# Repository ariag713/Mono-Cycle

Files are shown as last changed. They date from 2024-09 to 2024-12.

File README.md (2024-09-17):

# Mono-Cycle

## Description
  The monocycle will be a remote controlled unmanned vehicle (drone), that will drive on one wheel.
  Realistically the entire build will be a wheel with electronics in it.
  The drone will be able to balance on its own while stationary and in movement.
  The drone will be built in three main assemblies
  * The drive wheel
    * A ring gear with teeth on the inside of the ring and on the outside of the ring will be a layer of rubber or 3d printed filamnent (that has some spring to it)
    * The outside of the ring will have rounded edges to simulate a bicycle wheel. This will also help in cornering and turning
  * The drive housing
    * The drive housing is what is going to store all the electronic components that allow this vehicle to move.
    * The drive motor will rotate the tread around the drive housing to allow the drone to move.
    * It will also hold some support gears to keep the tread from slipping, and provide required tension to the tread to also prevent it from slipping
    * It will also house the gyroscopic actuator that will allow the unit to have controlled tilt
  * The load housing
    * for the final product, the load housing will be important for its practical usage.
    * The load housing will have the components required to keep the load balanced while the drone is in operation.
    * It will help mitigate the roll the load will receive upon acceleration and deceleration/braking.

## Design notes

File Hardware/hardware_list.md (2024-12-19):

*Here is the list for the Hardware component*
# Hardware
* Measurement: 20 inchs height
* Jump wires and solid core wires

### Craft
* Controller
  * [Mobile device with access to Arduino Bluetooth Controller](https://play.google.com/store/apps/details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)
* Housing:
  * [3d printed - using whole roll of filament](https://www.amazon.com/ELEGOO-Filament-Dimensional-Accuracy-Cardboard/dp/B0BM739JRF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) -price: $19.99
* Power Supply:
  * Primary: 
    * [6 AA battery pack](https://www.amazon.com/Coppertop-Batteries-Ingredients-Long-lasting-Household/dp/B000IZQO7U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) - price: $7.29
  * Secondary:
    * [Li battery pack for boost module and recharging](https://www.amazon.com/Replacement-Bluetooth-Controller-Generation-Playstation-4/dp/B07K8C6HGT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) - price: $ 13.39
    
* Boost Module:
  * [MT3608](https://www.amazon.com/Converter-Adjustable-Voltage-Regulator-Compatible/dp/B089JYBF25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) - price: 6.99
   * Specifications:
    * Input Voltage: DC 2V-24V
    * Output Voltage: DC 5V-28V
    * Maximum Output Current: 2A
    * Maximum Conversion Efficiency: 93%
    * Board Size: 36 X 17 X 14mm/1.42 X 0.67 X 0.55inch(L*W*H) 
* Microcontroller:
  * [Arduino Uno R3](Datasheets/ArduinoR3-datasheet.pdf) -price: 16.99
* DC Motor:
   * [DC motor with gearbox](https://www.amazon.com/dp/B08CMPBXNL?ref=ppx_yo2ov_dt_b_fed_asin_title&th=1) - price: 9.99
    * Specifications:
     *  Brand: 	‎Gebildet
     * Weight: 8.47 Ounces
     * Dimmensions: 0.86"W x 0.86"H
     * Operating voltage: 3V~12VDC
     * Type: 1:48 gear ratio
* Transciever
   * [HC-05 Bluetooth Module](Datasheets/HC-05_Datasheet.pdf) - price: $9.99

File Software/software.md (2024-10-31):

*Here is the list for the software*
# Software
- PC Software:
  * Arduino IDE:
    * The Arduino IDE is a cross-platform application used to write, compile, and upload code to Arduino boards. It features a simple             interface for writing C/C++-based "sketches," with a code editor, syntax highlighting, and a serial monitor for debugging. The IDE 
      includes a library manager for additional functions and simplifies programming by providing pre-written libraries and easy USB 
      uploads to the board.
      
- Mobile Software
  * Arcuino Bluetooth Controller
    * The Arduino Bluetooth Controller App allows wireless control of Arduino     projects via Bluetooth from an Android device. It 
      supports multiple modes, such as button, joystick, and terminal, enabling users to send commands to control motors, lights, or other 
      connected components. Ideal for remote control, robotics, or home automation projects, it simplifies Bluetooth communication with 
      Arduino using modules like HC-05.

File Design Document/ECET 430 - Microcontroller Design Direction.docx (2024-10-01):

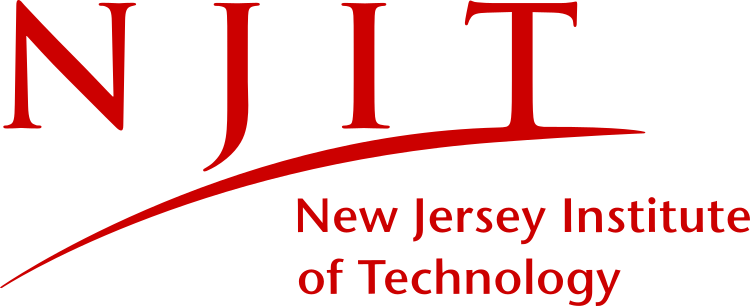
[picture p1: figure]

# Microcontroller Design Direction

Christian Hansis

Students:

Arturo Garcia

Joao Sarmiento

Jeury Abreu

2024-09-31

# Microcontrollers:

## 1. Arduino Uno:

- Arduino UNO is a microcontroller board based on the ATmega328P. It has 14 digital input/output pins (of which 6 can be used as PWM outputs), 6 analog inputs, a 16 MHz ceramic resonator, a USB connection, a power jack, an ICSP header and a reset button.

## 2. S32:

- The S32 chip refers to a family of microcontrollers and processors developed by NXP Semiconductors, designed specifically for automotive, industrial, and safety-critical applications. The S32 family is known for its high-performance, real-time capabilities and its support for automotive-grade standards such as ISO 26262.

## 3. ESP 32:

- ESP32 is a chip that provides Wi-Fi and (in some models) Bluetooth connectivity for embedded devices – in other words, for IoT devices. While ESP32 is technically just the chip, the modules and development boards that contain this chip are often also referred to as “ESP32” by the manufacturer.

# Pros and Cons:

## Arduino Uno (Atmega328P):

Pro | Con
Beginner Friendly | Limited Processing Power (Single-Core 16MHz)
Versatile and Well-Supported | Limited Memory(2KB SRAM, 32KB Flash, 1KB EEPROM)
Affordable | No Built-in Wi-Fi or Bluetooth
Extensive Shield Ecosystem | Limited I/O Pins
Open-Source Hardware and Software | No Real-Time Operating System (RTOS)
Low Power Consumption | Not Ideal for Resource Heavy Projects
USB Powered

## S32:

Pro | Con
Automotive-Grade Quality | High Complexity
High Performance | Higher Cost
Scalability | Overkill for Non-Automotive Applications
Real-Time Processing | Development Complexity
Advanced Security Features | Longer Development Cycle
Power Efficiency | Power Consumption in High-Performance Modes
Wide Ecosystem Support | Limited Availability in Consumer Markets

## ESP32:

Pro | Con
Wi-Fi and Bluetooth Connectivity | Complexity
Dual Core Processor | Limited Pin Availability
Low-Cost | Limited Ram (520 KB SRAM)
GPIO and Peripheral Support | Overheating Under Heavy Load
Low Power Consumption modes | High Power Consumption in Active Mode
Open Source SDK | Steeper Learning Curve
Built-in Security Features | Software Complexity

# Decision:

- Our decision is to use the Arduino Uno for our Mono-wheel as it is a good choice for simple, small-scale projects, especially for beginners due to its affordability, ease of use, and extensive community support. It’s ideal for basic tasks, low-power applications, and projects that don't require significant processing power, memory, or multitasking.

# Use of Resources from Microcontroller:

### 1. Motor Control (PWM via Timer):

Resource: Digital I/O Pins (PWM Capable), Timer1

#### PWM Parameters for Mono-Wheel Motor:

- Duty Cycle: The duty cycle controls the speed of the mono-wheel motor by adjusting the average voltage supplied to the motor. The duty cycle is a percentage of time the signal stays HIGH (on) versus LOW (off).
  - Initial Duty Cycle: Start with 50% (0.5) for testing.
  - Adjustable Duty Cycle: Can range between 0% (full stop) to 100% (full speed).
- Frequency: The frequency determines how fast the PWM signal switches between HIGH and LOW.
  - For motor control, a typical frequency is in the range of 500 Hz to 1 kHz, as lower frequencies can cause the motor to produce audible noise.
  - Chosen Frequency: 1 kHz for smoother motor control and less noise.

#### Arduino Uno PWM Pin:

- The use pin D9, which is one of the PWM-capable pins connected to Timer1. Timer1 is 16-bit, so it gives better control over the PWM signal compared to Timer0 and Timer2, which are 8-bit.

2. Direction Control (Digital Output Pins):

Resource: Digital I/O Pins (GPIO)

- The motor’s direction will be controlled by an H-Bridge driver ( L298N), which requires two digital pins to set the direction (forward or backward).

#### Pin Assignment for Direction Control:

- Pin D7: Forward direction
- Pin D8: Reverse direction

#### Parameters:

- The logic for these pins is binary:
  - Forward: D7 = HIGH, D8 = LOW
  - Reverse: D7 = LOW, D8 = HIGH

### 3. Sensor Feedback (Analog Input for Stability):

Resource: Analog I/O Pins

- For the mono-wheel’s balance and stability, I will use an IMU (Inertial Measurement Unit) or accelerometer/gyroscope combination, connected to the analog inputs.

#### Pin Assignment:

- Pin A0 and A1: Used for analog input from the IMU (for X and Z axis).

#### Parameters:

- The IMU will provide feedback on the tilt and orientation of the mono-wheel. This data will be used to adjust the motor speed and direction to maintain balance.

### 4. User Input (Potentiometer for Speed Control)

Resource: Analog Input or Digital Input

- A potentiometer will allow the user to manually control the speed of the mono-wheel by adjusting the PWM duty cycle.

#### Pin Assignment:

- Pin A3: Analog input for the potentiometer (speed control).

#### Parameters:

- The potentiometer will adjust the motor speed by changing the duty cycle of the PWM signal.
- Output Voltage Range: 0-5V (corresponds to 0%-100% duty cycle).

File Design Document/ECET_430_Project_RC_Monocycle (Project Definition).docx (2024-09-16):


# ECET 430 -

# Remote Controller Monocycle

Christian Hansis

Students:

Arturo Garcia

Joao Sarmiento

Jeury Abreu

2023-08-24

# Client

- contact information.-
  - Arturo Garcia
    - arg68@njit.edu
    - 856-558-0271

Joao Sarmiento

    - js2669@njit.edu
    - 201-772-9021

Jeury Abreu

    - ja528@nit.edu
    - 732-925-7059

# Communication

Regarding communication we as a team have our own discord chat where we discuss anything relating to our project. We created a todo list to make sure that we are going in the same path and also clarifying any dude or concern, also to make easy for us in what part are working or what is missing, for this last feature mentioned we are using Github In addition, we are filling all the stuff regarding hardware even software in our team Github logbook

# Objectives

DESCRIPTION:

Our product is basically inspired by a MIB (Men in Black) vehicle. The concept of this product is similar to that vehicle, it is a self-stabilized unicycle where the active driving area is around the payload/core of the cycle and it is also manageable by a remote control which will play a crucial role in the performance of our product. The particularity of the design which demonstrates the innovation in our product itself and also brings a new idea to the public. To add, this product is aimed at people of any age. We have in mind to create two models, the first one in mind would be the simplest implemented for the aforementioned, and the second would provide certain features such as a camera and a speaker included to connect Bluetooth equipment and also the remote control would also have variations such as the implementation of a screen in it, basically, assimilating the functions of a drone.

# Scenario

## User Interaction Stories

When you receive your product basically you will get a very detailly box with images referring to our product. When you open it, you will see the remote controller packed in its own box, inside it it will be covered with a bubble bag, then you will find the monocycle also inside in a separate box and also cover for a bubble bag. Besides, you will also find a manual, this will guide you on how to use it and how to install the batteries for the monocycle and the remote controller, the basics functionalities and the proper ways to use it. Relating to use, once you put the batteries on product and remote controller you will manipulate thru RC the product, it basically gives you the entertainment of a RC car, But the difference or the fun part here will be to see how it moves forward or backward and even when it makes turns, that is what makes it innovative and outstanding compared to conventional RC cars. Regarding troubleshooting, if an problem exists the product contains replacement for the wheel, and for the RC, in the manual explain how replace the damage part, is not too difficult to solve by ourselves, in addition, the product have a 1 year guarantee which cover any problem relate to RC or the product itself.

## User Interface

In terms of user interface, as mentioned before our product will have two versions, one with a display in the controller and the other without it. Basically, both versions in the remote controller will not have a button, but it will have a joystick whose functionality will consist in guiding the craft to the direction desired, also will count with an on/off switch for craft and controller. Also an indicator will be added as a proof that the craft is on or off also the controller will have one with the same functionality.

# User Acceptance

- Given-When-Then criteria
  - when craft is active,it should auto balance
- quantifiable goals

# Parameters

## Technical

- dimensions .- 21x10x5 cm or 8.3x3.9x2 in
- weight.- 500g or 1.1 pound
- Electromagnetic compatibility (EMC) and electromagnetic interference (EMI)
- protection

## Functions

Our product will have main functions that will make it a unique model, the main functions are self-balancing, with this function it will be easier to manipulate and handle it with this functionality it will provide greater comfort and fun to the user. The other function is to be able to get up again after a fall, this function is basically when the user collides with a structure, after the impact the vehicle will return to its initial position. Another function is the ability to go forward and backward, either for the comfort of the user. Our product offers the ability to go forward and backward correctly to provide a great maneuverability experience of our product. The other function of this product is to keep the load (core) stable and the track is what moves, this means that while the vehicle is in motion the core and what is inside it will remain stable while the tire or belt that surrounds it is what moves. and the last function refers to the automatic accelerator and manual accelerator options, this is basically to provide greater entertainment to the user who, if he wants can accelerate with the remote control or the vehicle itself can accelerate on its own.

## Integration

Interface

it counts with a bluetooth system incorporated and also a remote controller which will be the mechanism to make it work. (app?)

## Operational

- restrictions. - No restrictions
- duty cycle. - The battery life expectation of our product is 7 hours after charge, and the charge process of it is around 2 to 3 hours to fully charge.

## Regulatory

- laws
- regulations
- policies

## Life Cycle

- manufacturing.-
- programming
- tracking
- service
- associated services

# Environment

Our product has the ability to work in different types of environments, the temperature ranges in which it will work are between 14 degrees Fahrenheit and 110 degrees Fahrenheit, below 14 degrees Fahrenheit it might not work very well due to the low temperature which damages some cables, the same happens in temperatures above 110, some cables and components may start to melt.The product should avoid smooth surfaces as it will be difficult to drive properly and could also damage the core due to the constant dangers of falling due to these surfaces. Also, as an electronic device, you should avoid water as water will destroy all the internal components and render it useless.

- power.- it will count with a 4V 1200mAh Li-Ion Battery implemented to the craft. The purpose of using this battery is that it is reliable, very durable, easy to get a replacement and also easy to replace.

# Starting Point

- existing prototypes

https://www.instructables.com/Making-a-Monowheel/

In the link above is a prototype of our project but on a big scale and using foundations of mechanics, basically from this we just use the idea of how our project will look.

https://youtu.be/fIADzTanDo8?si=Uh0wI1ux-ViAeKzg

And from this link we will get an idea of how to use the appropriate wiring and how our project will work and the functionalities it will have. In addition, we will add the rest of the elements mentioned above to give it a different and innovative look.

# Key Concerns

The most important thing that we can observe in our product is basically what refers to self-balancing, it is possibly the most important feature that we can appreciate, another one that we could talk about is the distance between the remote control antenna and the vehicle receiver, they can communicate with each other for a better experience, another important point is the sideways turn or rather the turns, and the self-balancing also depends a lot on this, which would allow the product to have perfect stability and avoid any unforeseen event when trying to turn right or left or a total turn (180 or 360 degrees)

# Future

- plans
- ideas

# Glossary

- common vocabulary
- project specific terms

# Open Questions

to be discussed with team/clien

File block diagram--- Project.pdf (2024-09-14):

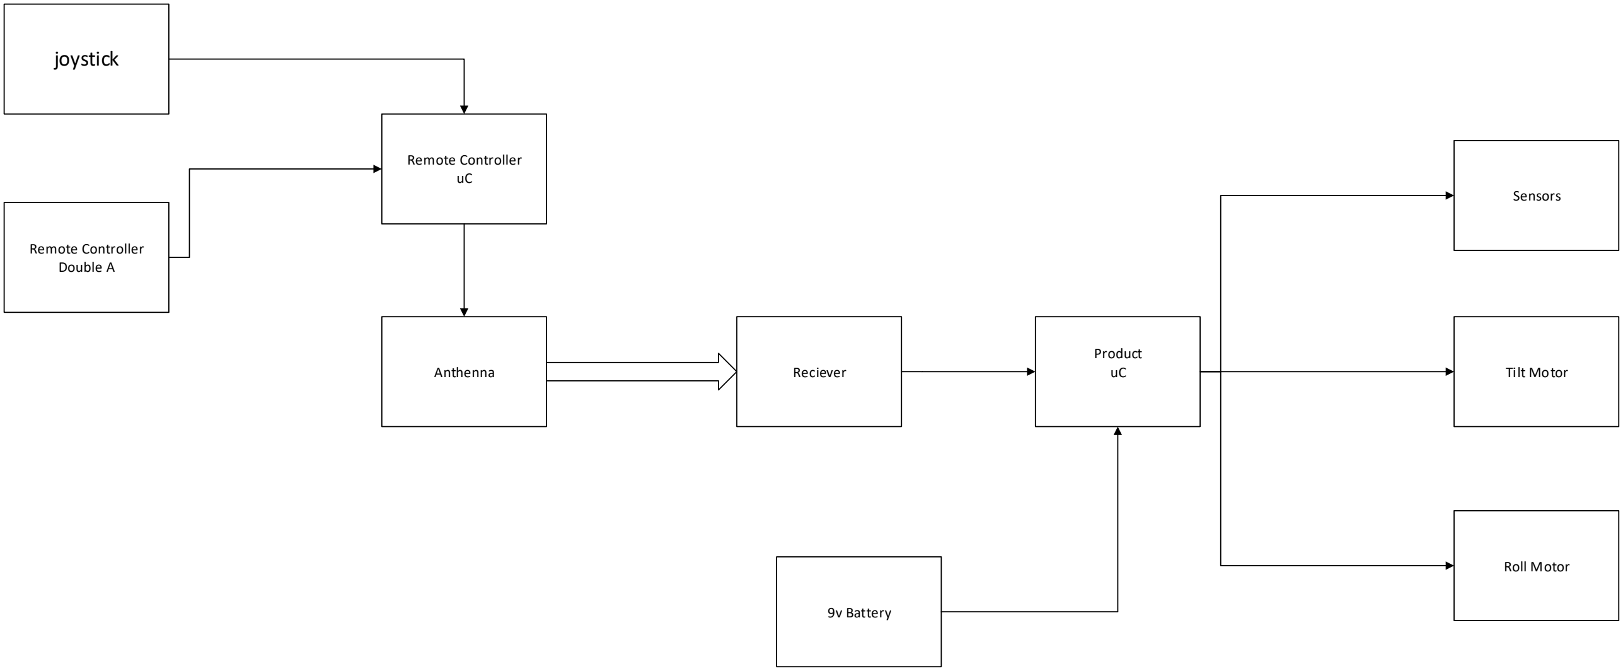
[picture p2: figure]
joystick; Remote Controller uC; Remote Controller Double A; Anthenna; Sensors; 9v Battery; Product; Reciever; Tilt Motor; Roll Motor

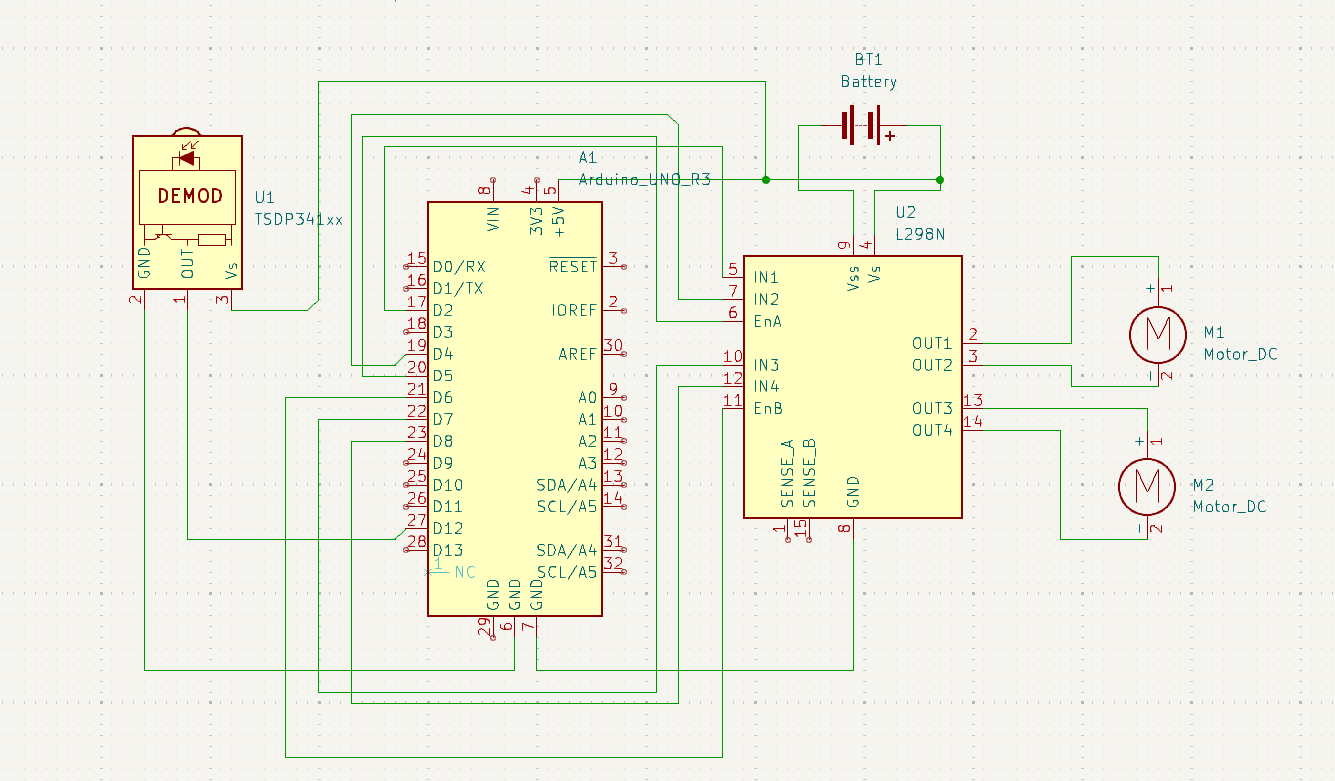
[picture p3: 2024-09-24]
schematics/v1.0/Craft_Schematic.png

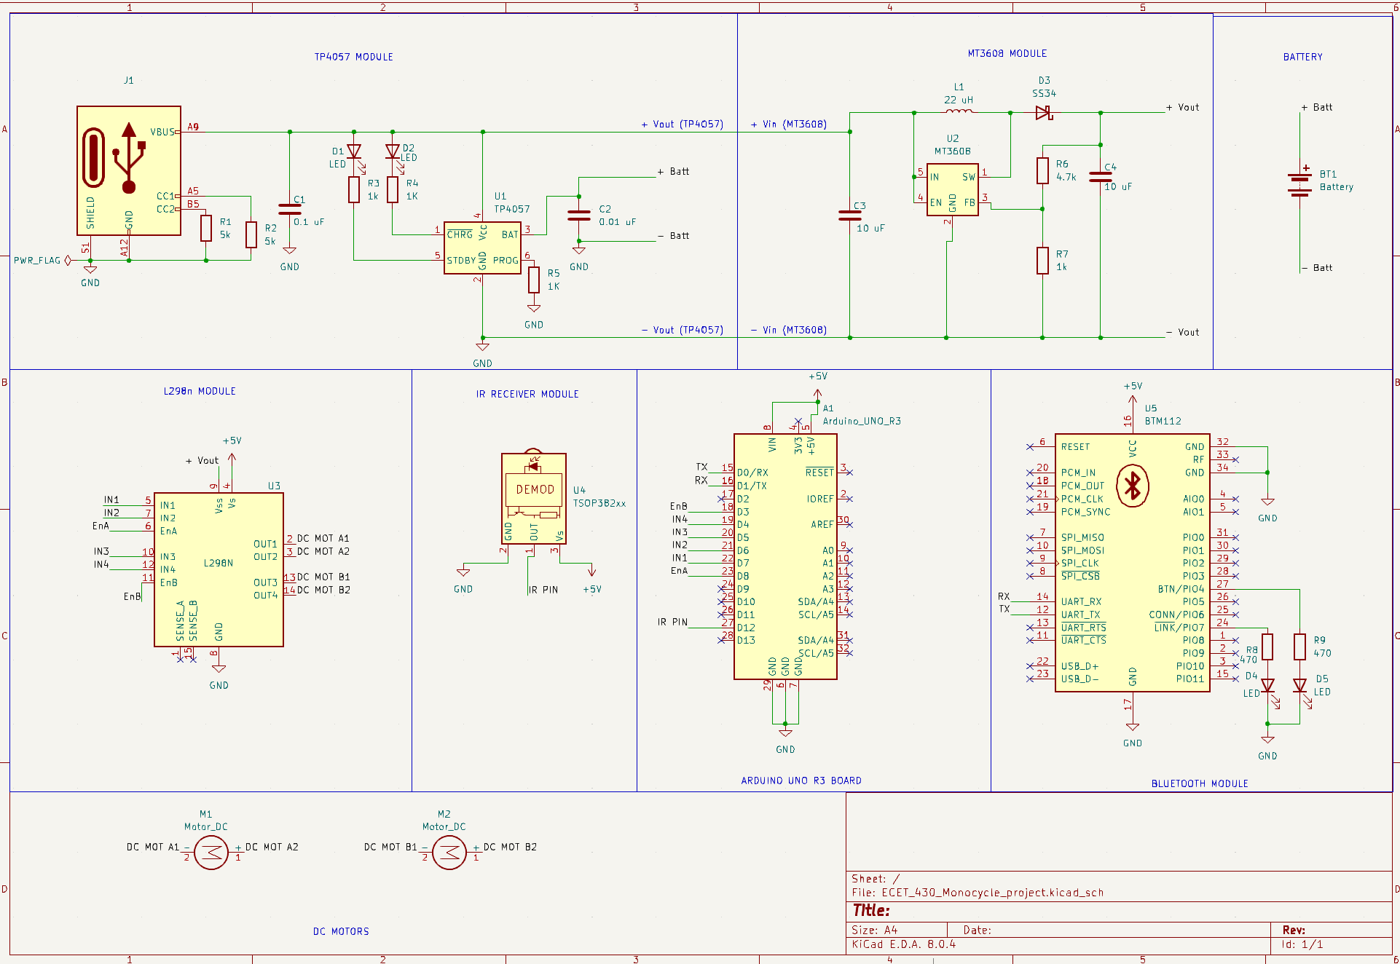
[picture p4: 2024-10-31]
schematics/Monocycle1.5/Monocycle_Project_Schematic.png

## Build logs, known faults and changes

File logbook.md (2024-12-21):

# Logbook

## Mono-Cycle Project

### **09/10/24**
- Defined the project scope and objectives for the Monocycle. Outlined the functional and performance requirements to ensure clarity of the project goals.

### **09/16/24**
- Major moving parts for the Monocycle were carefully selected based on durability, performance, and compatibility with the design specifications.

### **09/24/24**
- Created the initial schematic for the microcontroller, focusing on the basic circuit design to support motor control and integration with peripheral components.

### **09/27/24**
- Procured key components including DC motors and an H-bridge motor driver. These arrived and were prepared for integration and testing with the microcontroller.

### **10/08/24**
- Conducted preliminary tests on the motors to evaluate their basic movements. Using a serial monitor, verified forward, backward, left-turn, and right-turn functionalities.

### **10/15/24**
- Concluded the motor movement tests successfully. All directions and functionalities performed as expected, confirming the motors and driver were operational.

### **10/17/24**
- Updated the schematic to include new components: a booster module to regulate voltage, an HC-05 Bluetooth module for wireless control, and a type-C battery charger for efficient power management.

### **10/21/24**
- Integrated the booster module into the circuit to raise the voltage to 10V using a voltage regulator. Also connected a battery charger to streamline the power supply system.

### **10/29/24**
- Began the look-like design phase in Autodesk Fusion, focusing on creating a model that resembles the final product. Continued material selection for construction and assembly.

### **11/04/24**
- Implemented the HC-05 Bluetooth module with Arduino for wireless motor control. Wrote and ran code to integrate the L298N motor driver, enabling PWM control for precise motor speed adjustments.

### **11/10/24**
- Started configuring the HC-05 Bluetooth module for serial communication with Arduino. During testing, identified an issue where the booster module was not supplying adequate current.
- Planned to replace the power supply with a higher-current battery setup (6 AA batteries in series) to resolve the issue.

### **11/12/24**
- Designed the initial monowheel housing. After peer review and discussion, identified areas for improvement, leading to plans for redesign.
- Replaced the power supply with a battery pack of 6 AA batteries to meet the current requirements of the motor driver.

### **11/19/24**
- Decided to order and integrate a gearbox with the DC motor for improved speed control and reduced rotational speed. Initiated redesign of the housing to accommodate the new gearbox.

### **11/26/24 to 11/28/24**
- 3D-printed the monowheel housing into modular parts, allowing for easier assembly and troubleshooting.
- Started drafting the project report, documenting progress and insights. Planned to finalize it after the complete assembly and testing of the Monowheel.

### **12/03/24 to 12/10/24**
- Received the gearbox motors on schedule. Proceeded with final prototype assembly.
- Utilized the MakerSpace soldering station for precise and reliable connections during the final assembly.
- Encountered errors in the initial code during testing. Troubleshot and implemented corrections, successfully resolving the issues.

### **12/17/24**
- Fully assembled the Monowheel and conducted final testing. All tests were passed without issues, confirming the success of the project.
  - **Test 1: Mechanical Functionality** ---- PASS ----
  - **Test 2: Turning Radius and Control** ---- PASS ----
  - **Test 3: Bluetooth Connectivity and Stability** ---- PASS ----
- Final prototype successfully meets project goals and specifications.

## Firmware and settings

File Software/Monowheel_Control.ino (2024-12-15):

#include <AFMotor.h>
#include <stdio.h>
// Define motor pins
#define mrA1 7 // IN1
#define mrA2 6 // IN2
#define mrB1 5 // IN3
#define mrB2 4 // IN4
#define ENA 8     // PWM for motor A
#define ENB 3     // PWM for motor B

int speedr;
char command;
char pcom;
char ppcom;
//Pin Communication and Set Up
void setup() {
  Serial.begin(9600); // Start Bluetooth communication
  pinMode(mrA1, OUTPUT);
  pinMode(mrA2, OUTPUT);
  pinMode(mrB1, OUTPUT);
  pinMode(mrB2, OUTPUT);
  pinMode(ENA, OUTPUT);
  pinMode(ENB, OUTPUT);
}
//Motor control settings
void setf() {
  digitalWrite(mrA1, LOW);
  digitalWrite(mrA2, HIGH);
  digitalWrite(mrB1, HIGH);
  digitalWrite(mrB2, LOW);
}
void setb() {
  digitalWrite(mrA1, HIGH);
  digitalWrite(mrA2, LOW);
  digitalWrite(mrB1, LOW);
  digitalWrite(mrB2, HIGH);
}
void setL() {
  digitalWrite(mrA1, LOW);
  digitalWrite(mrA2, HIGH);
  digitalWrite(mrB1, LOW);
  digitalWrite(mrB2, HIGH);
}
void setR() {
  digitalWrite(mrA1, HIGH);
  digitalWrite(mrA2, LOW);
  digitalWrite(mrB1, HIGH);
  digitalWrite(mrB2, LOW);
}
void STOP() {
  digitalWrite(mrA1, LOW);
  digitalWrite(mrA2, LOW);
  digitalWrite(mrB1, LOW);
  digitalWrite(mrB2, LOW);
  analogWrite(ENA, 0);
  analogWrite(ENB, 0);
}
void controlMotors(char command) {
  switch (command) {
    case 'F':
      slowDown(speedr);
      setf();
      accelUp(speedr);
      break;
    case 'B':
      slowDown(speedr);
      setb();
      accelUp(speedr);
      break;
    case 'R':
      slowDown(speedr);
      setR();
      accelUp(speedr);
      break;
    case 'L':
      slowDown(speedr);
      setL();
      accelUp(speedr);
      break;
    case 'S':
      STOP();
      break;
  }
}
//Speed control
void accelUp(int speedr) {
  int i;
  for (i = speedr; i < 255; i += 5)
  {
    speedr = i;
    //printf(speedr);
    analogWrite(ENA, speedr);
    analogWrite(ENB, speedr);
    delay(10);
  }
}
void slowDown(int speedr) {
  int i;
  for (i = speedr; i > 0; i -= 5)
  {
    speedr = i;
    //printf(speedr);
    analogWrite(ENA, speedr);
    analogWrite(ENB, speedr);
    delay(10);
  }
}

void loop() {
  if (Serial.available()) {
    char command = Serial.read(); // Read command from Bluetooth
    controlMotors(command);
  }
}

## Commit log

2024-09-24 Update and rename Remote_Controller_Schematic.kicad_sch to schematics/Remote_Controller_Schematic.kicad_sch
    [Remote_Controller_Schematic.kicad_sch]
2024-09-24 Update and rename schematics/Remote_Controller_Schematic.kicad_sch to schematics/v1.0/Remote_Controller_Schematic.kicad_sch
    [Remote_Controller_Schematic.kicad_sch]
